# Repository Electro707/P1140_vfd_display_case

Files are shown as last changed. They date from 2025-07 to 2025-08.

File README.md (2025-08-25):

# P1140 - 2x20 VFD Display Enclosure+Driver

This project is my enclosure, Pico code, and PC software for a
CU20029-UW1J Vacuum Fluorescent Display I got a hold of.

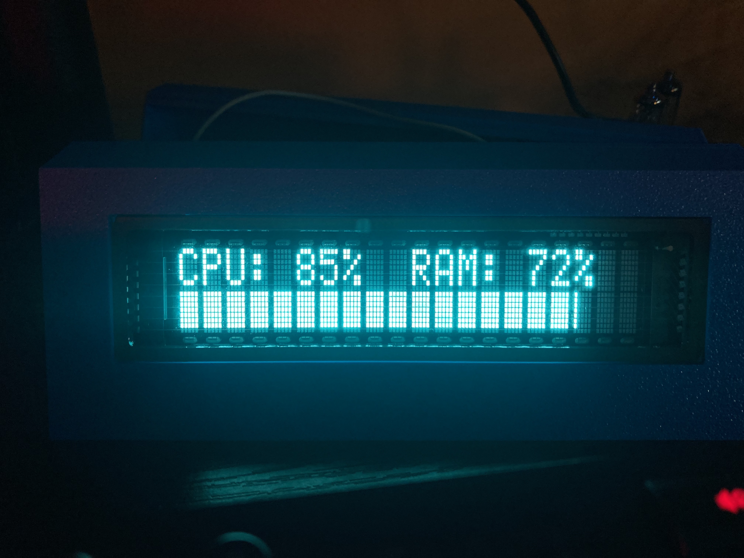
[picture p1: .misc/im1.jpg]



# BOM
- CU20029-UW1J VFD Display
- Raspberry PI Pico, Original
- 13x Female-Female Jumpers, ~3in
- 3D printed parts from this project, C1141 to C1143

## Wiring

The following is the wiring between the Pico and the display:

|---------|------------|
| Pico IO | Display IO |
|---------|------------|
| 0       | DB0        |
| 1       | DB1        |
| 2       | DB2        |
| 3       | DB3        |
| 4       | DB4        |
| 5       | DB5        |
| 6       | DB6        |
| 7       | DB7        |
| 8       | E          |
| 9       | RW         |
| 10      | RS         |
|---------|------------|

# Parts
- C1141 Rev A: Enclosure, front
- C1142 Rev A: Enclosure, back
- C1143 Rev A: Enclosure, Pico Holders
- F1145 Rev A-dev: PI Pico Firmware
- S1146 Rev A-dev: Python PC Software, multiple

# License

This entire project is licensed under [GPLv3](LICENSE.md)

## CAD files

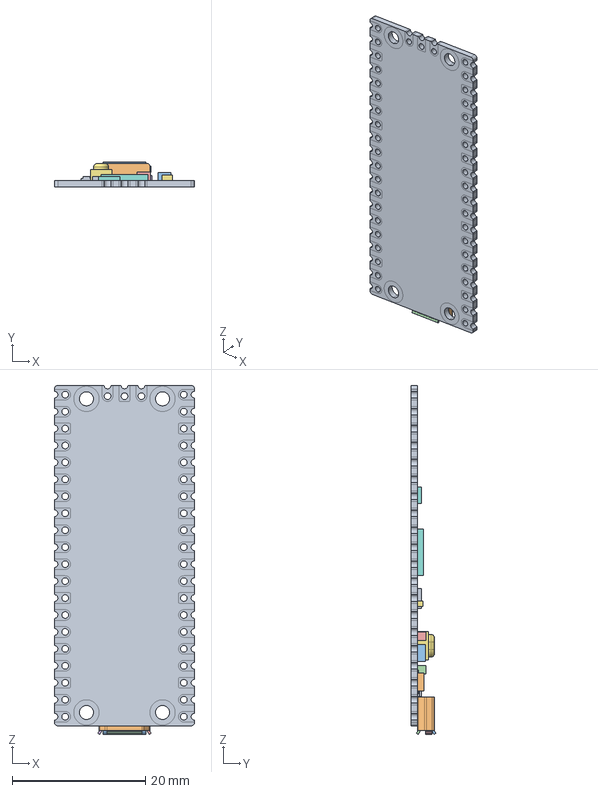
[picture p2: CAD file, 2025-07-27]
CAD/Pico-R3.FCStd
21.0 x 3.73 x 52.3 mm
PICO_REF_BOARD.STEP
PICO_REF_USB.STEP
PICO_REF_USB.STEP001
PICO_REF_USB.STEP002
PICO_REF_USB.STEP003
PICO_REF_USB.STEP004
PICO_REF_SWITCH.STEP
PICO_REF_MICROCONTROLLER.STEP
PICO_REF_LED.STEP
PICO_REF_ONSEMI.STEP
PICO_BOURNS.STEP
PICO_MURATA.STEP
PICO_MURATA.STEP001
PICO_RICHTEK.STEP
PICO_DIODES.STEP
PICO_AEL.STEP
PICO_WINBOND.STEP

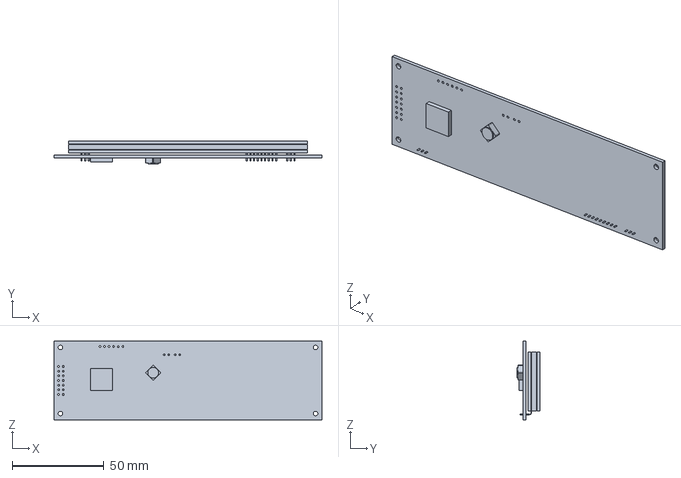
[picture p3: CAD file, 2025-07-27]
CAD/Display.FCStd
146.0 x 12.7 x 43.0 mm

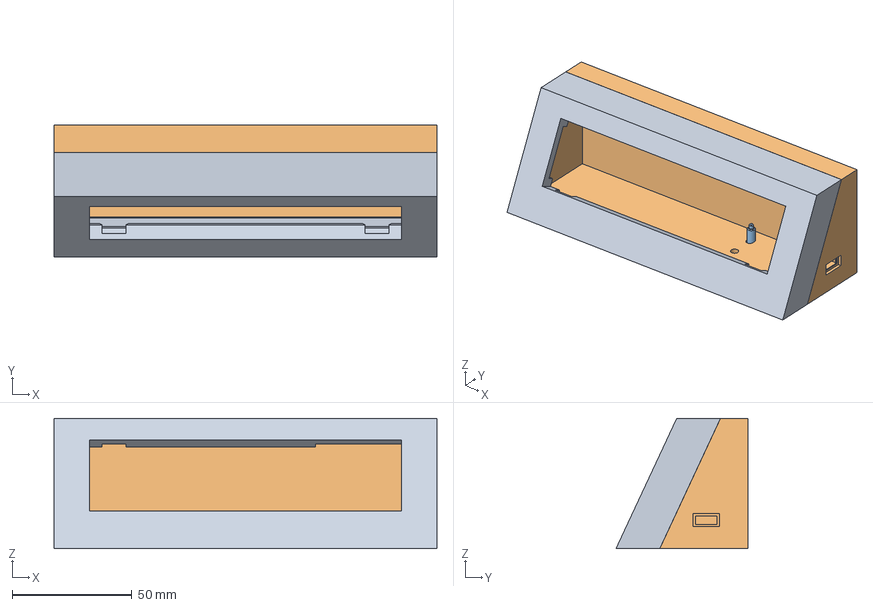
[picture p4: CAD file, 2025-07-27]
CAD/C114x.FCStd
160.2 x 55.2 x 54.4 mm
C1141
C1142
C1143

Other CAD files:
CAD/ASSY.FCStd

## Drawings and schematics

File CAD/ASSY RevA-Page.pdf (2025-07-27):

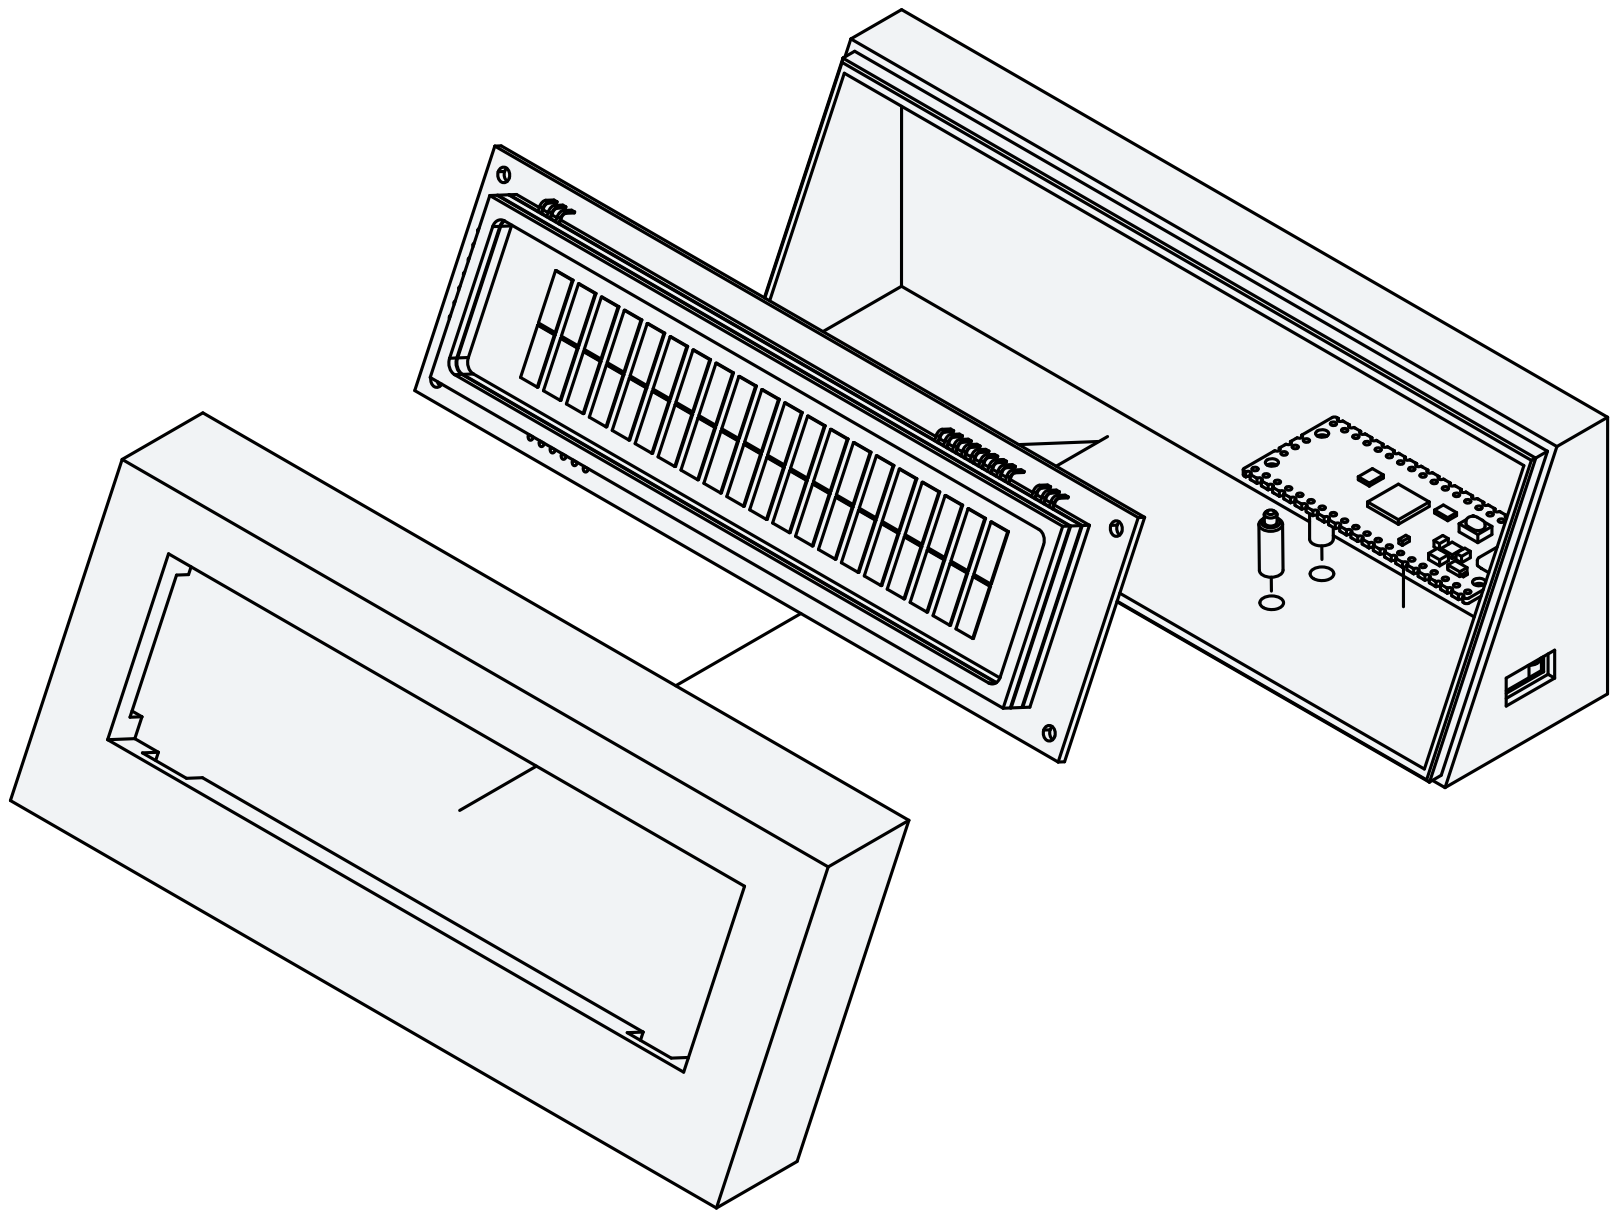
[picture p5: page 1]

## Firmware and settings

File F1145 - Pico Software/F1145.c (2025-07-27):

#include <stdint.h>
#include <stdio.h>
#include "pico/stdlib.h"
#include <pico/time.h>

#define PIN_RS  10
#define PIN_RW  9
#define PIN_E   8

#define DISPLAY_WIDTH   20

#define CUST_CMD_START  0x02

#define EVER    ;;

void dispSend(uint8_t b, bool rs);
void dispInit(void);
void dispHome(void);
void dispClear(void);
void dispWrite(const char *text);
void dispBrightness(uint8_t b);
void handleCommand(uint8_t cmd);

bool clearOnLn = true;     // false for only home on \n, true to clear
int currCol = 0;

int main()
{
    stdio_init_all();

    // PGIO0 to 10 are used for the display, set all to out
    gpio_set_function_masked(0x7FF, GPIO_FUNC_SIO);

    gpio_set_dir_out_masked(0x7FF);

    gpio_put(PIN_E, 0);

    dispInit();

    dispClear();
    // dispHome();
    // dispWrite("Hello!");
    // printf("Hello, world!\n");

    
    bool clearOnNext = false;
    bool cmdOnNext = false;
    for(EVER){
        char r = getchar();
        // if we get new line, set for next time to clear the display
        if(r == '\r' || r == '\n'){
            clearOnNext = true;
            continue;
        }
        if(r == CUST_CMD_START){     // if escape, we do our own command on next read
            cmdOnNext = true;
            continue;
        }

        if(cmdOnNext){
            handleCommand(r);
            cmdOnNext = false;
            continue;
        }
        
        if(clearOnNext){
            clearOnLn ? dispClear() : dispHome();
            clearOnNext = false;
            currCol = 0;
        }

        dispSend(r, 1);
        currCol++;
        if(currCol > DISPLAY_WIDTH){
            dispSend(0xC0, 0);   // move to next line
            currCol = 0;
        }
    }
}

void handleCommand(uint8_t cmd){
    bool ack = true;
    // set new line to clear display
    // 0x30 to 0x58 are to set the cursor position
    if(cmd >= 0x30 && cmd <= (0x30+(DISPLAY_WIDTH*2))){
        cmd -= 0x30;
        if(cmd >= DISPLAY_WIDTH){
            cmd -= DISPLAY_WIDTH;
            cmd |= 0x40;
        }
        currCol = cmd & 0x3F;
        dispSend(0x80 | cmd, 0);   // move to next line
    }
    //0x2C to 0x2F is for brightness
    else if(cmd >= 0x2C && cmd <= 0x2F){
        cmd -= 0x2C;
        dispBrightness(cmd);
    }
    else{
        switch(cmd){
            case 'c':
                clearOnLn = true;
                break;
            case 'h':
                clearOnLn = false;
                break;
            case 'x':
                dispClear();
                break;
            default:
                printf("nack\n");
                ack = false;
                break;
        }
    }

    if(ack){
        printf("ok\n");
    }
}

void dispClear(void){
    dispSend(0x01, 0);      // set address to 0
    currCol = 0;
    sleep_us(200);
}

void dispHome(void){
    dispSend(0x02, 0);      // set address to 0
    currCol = 0;
}

void dispWrite(const char *text){
    while(*text){
        dispSend(*text, 1);
        text++;
    }
}

void dispBrightness(uint8_t b){
    b &= 0x3;       // limit from 0 to 3

    dispSend(0x33, 0);      // set mode to 4 bits
    dispSend(b, 1);      // 100% brightness, must come after function set
}

void dispInit(void){
    dispSend(0x33, 0);      // set mode to 4 bits
    dispSend(0x00, 1);      // 100% brightness, must come after function set

    dispSend(0x01, 0);      // clear display
    sleep_ms(5);

    dispSend(0x02, 0);      // cursor home
    dispSend(0x0c, 0);      // turn display on
    dispSend(0x06, 0);      // mode entry, addr is incremented and cursor shift
}

// sends a byte to the display
// rs is whether to toggle the RS pin high or low, and b is the data
void dispSend(uint8_t b, bool rs){
    gpio_put(PIN_RS, rs);

    gpio_put_masked(0xFF, b);
    gpio_put(PIN_E, 1);
    sleep_us(1);
    gpio_put(PIN_E, 0);

    sleep_us(5);     // average execution time
}

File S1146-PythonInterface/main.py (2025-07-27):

import time
import serial
import argparse
import psutil
import math

def main():
    parser = argparse.ArgumentParser(prog='Nixie Clock Driver')
    parser.add_argument('serPort')

    args = parser.parse_args()

    s = serial.Serial(args.serPort, baudrate=115200, timeout=0.5)

    s.write(b"\x02x")       # clear display
    s.write(b"\x02\x2E")       # 50% brightness
    s.write(b"\x02h")       # set so go to home on '\n'

    s.write(b"\x02\x30")
    s.write(b"CPU: ")
    s.write(b"\x02\x3A")
    s.write(b"RAM: ")
    time.sleep(1)

    # b = 0
    while True:
        try:
            cpuUsage = psutil.cpu_percent(interval=None)
            ramUsage = psutil.virtual_memory().percent

            s.write(b"\x02\x34")
            s.write(f"{int(cpuUsage):>3d}%".encode())

            s.write(b"\x02\x3e")
            s.write(f"{int(ramUsage):>3d}%".encode())

            s.write(b"\x02\x44")
            cpuUsageD = (cpuUsage / 100) * 20
            # for all full percentage, sent the filled character
            for i in range(int(cpuUsageD)):
                s.write(b'\x14')
            # for the fraction, send partial
            s.write((0x10+int((cpuUsageD % 1)*5)).to_bytes(1, 'big'))
            # for the rest, fill with 0
            for i in range(math.ceil(cpuUsageD), 20):
                s.write(b'\x00')

            # s.write(b'\x02' + (0x2C+b).to_bytes(1, 'big'))
            # b += 1
            # if b > 3:
            #     b = 0

            time.sleep(1)
        except KeyboardInterrupt:
            break

    s.write(b"\x02x")       # clear display
    s.close()

if __name__ == "__main__":
    main()

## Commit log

2025-07-27 Initial Release
    [ASSY.FCStd, C114x RevA.FCStd, Display.FCStd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]
2025-08-25 Added wiring diagram
2025-08-25 Renamed FreeCAD file
    [C114x.FCStd]
